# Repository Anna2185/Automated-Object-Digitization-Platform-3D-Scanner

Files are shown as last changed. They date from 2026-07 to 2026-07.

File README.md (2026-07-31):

## Copyright
Copyright © 2026 <b>AM G</b>. All rights reserved. 
This code is published strictly for portfolio demonstration and review purposes. No permission is granted to copy, modify, distribute or use this software for any other purpose.

# Automated Object Digitization Platform (3D-Scanner)
This project is a custom 3D scanner that uses an Arduino, a VL53L1X distance sensor, a stepper motor, and a servo motor. The stepper rotates the object while the VL53L1X measures the distance to the object. The servo then moves the sensor vertically using a linear actuator system so the object can be scanned one layer at a time.

The Arduino handles the physical scanning and sends the measurements to the computer through a serial connection. The Python program receives the data, converts it into 3D coordinates, and creates the different output files.

## Files
### hardware_control Folder
* **hardware_control.ino**: This is the arduino code. It controls the stepper motor, servo motor and VL53L1X sensor. It receives the object height from Python, performs the scan and sends the measurements back to the computer. The scanner takes a measurement every 5 degrees while rotating and moves up 1 mm after each full rotation.
### software_processing Folder
* **main.py**: This is the main Python file. It connects all of the other Python files together. It connects to the Arduino, asks for the object height, starts the scan, collects the data, and then creates the Excel file, point cloud, and STL file.
* **connection.py**: This handles the connection between the computer and Arduino. It finds the available serial ports and lets the user select whichever one is connected to the Arduino.
* **scanning.py**: This handles the scanning process on the Python side. It asks the user for the object height, sends the scan command to the arduino, and collects the measurements returned by the arduino. It also converts the distance measurements into X, Y, and Z coordinates.
* **point_cloud.py**: This handles the 3D point cloud. It displays the scanned points using Matplotlib and uses Open3D to clean up the point cloud and remove some of the noise. It also saves the cleaned point cloud as a PLY file.
* **excel_export.py**: This saves the scan data into an Excel file. The file includes the height, angle, measured distance, and calculated X, Y, and Z coordinates.
* **mesh.py**: This takes the cleaned point cloud and turns it into a 3D mesh using Open3D. The mesh is then exported as an STL file.
#### software_processing/archive/
* **FULL_3D_Scanner_Code.py**: This file is stored in an archive folder within the software_processing folder. It includes all the functions from the main.py, connection.py, scanning.py, point_cloud.py, excel_export.py and mesh.py files. This was the original file I coded in, then once everything was working, I separated all the files into parts to have better structure with actual functions and allow proper documentation.

## Pin Setup
### Stepper Motor (ULN2003 Driver)
* **VCC** -> + (battery 2)
* **GND** -> - (battery 2)
* **IN1, IN2, IN3, IN4** -> Arduino Digital Pins **D8, D9, D10, D11**

### VL53L1X Sensor
* **VCC** -> 5V (Arduino)
* **GND** -> GND (Arduino)
* **SDA** -> SDA (Arduino I2C Bus)
* **SCL** -> SCL (Arduino I2C Bus)
* **GPIO1** -> Arduino Digital Pin **D2**
* **XSHUT** -> 3.3V

### Servo Motor
* **VCC** -> + (battery 1)
* **GND** -> - (battery 1) & GND (Arduino)
* **Signal** -> Arduino Digital Pin **D6**

## How It Works
1. **Upload**: First, the user should open `hardware_control.ino` on Arduino IDE and upload the code to the actual Arduino board (have the board connected to your laptop prior to this)
2. **Launch**: Once that's done run `main.py` and select the Arduino's serial port. You will then be asked to enter the height of the object being scanned in cm
3. **Trigger**: Python sends the height to the Arduino using a command such as `SCAN:10`
4. **Scan**: The Arduino then scans the object by taking distance measurements every 5 degrees as the stepper rotates. After one full rotation, the servo moves the sensor up by 1 mm and the process repeats until the full height of the object has been scanned
5. **Stream**: The Arduino sends each measurement back to Python in the format of "height, angle, distance"
6. **Process**: Python converts these measurements into 3D coordinates and then uses them to create the point cloud and mesh

## Output
After the scan is finished, the program creates three main files:
* **scan_data.xlsx**: Contains the scan measurements and calculated coordinates.
* **clean_point_cloud.ply**: Contains the cleaned 3D point cloud.
* **scan_output.stl**: Contains the final 3D mesh.

## Running the Project
1. First upload `hardware_control.ino` to the Arduino and connect the Arduino to the computer
2. Make sure the required Python libraries are installed, then run: `main.py`
3. Select the Arduino's serial port and enter the height of the object when prompted. The scanner will then run automatically and generate the output files when it is finished

*Note: The current scanner is set up for a maximum object height of 15 cm, with 1 mm vertical resolution and measurements taken every 5 degrees around the object*

## Author
AM G. - [https://github.com/Anna2185](https://github.com/Anna2185?tab=repositories)

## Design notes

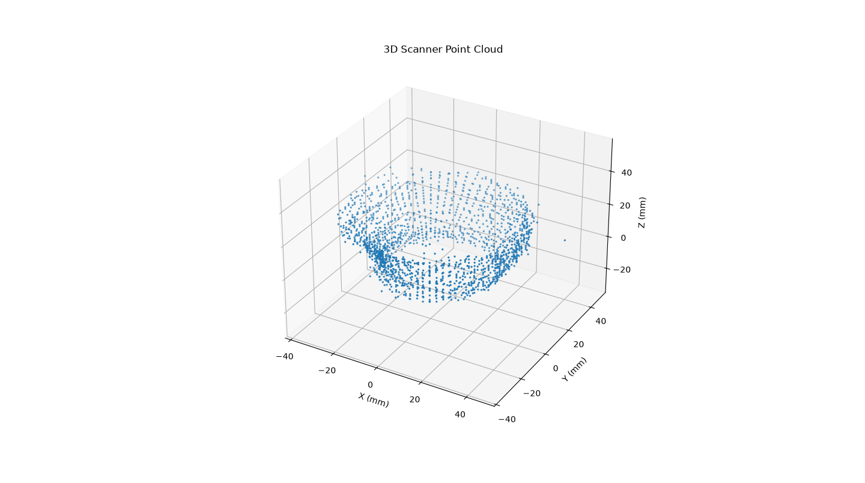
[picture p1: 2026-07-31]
output_samples/Graph Figures/Figure_3.png

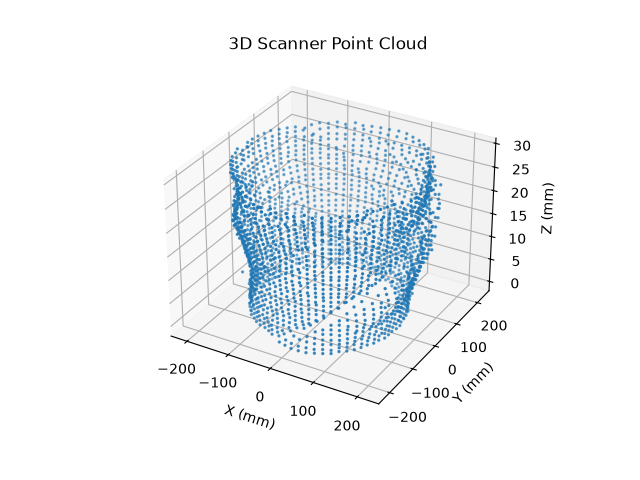
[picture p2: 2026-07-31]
output_samples/Graph Figures/Figure_1.png

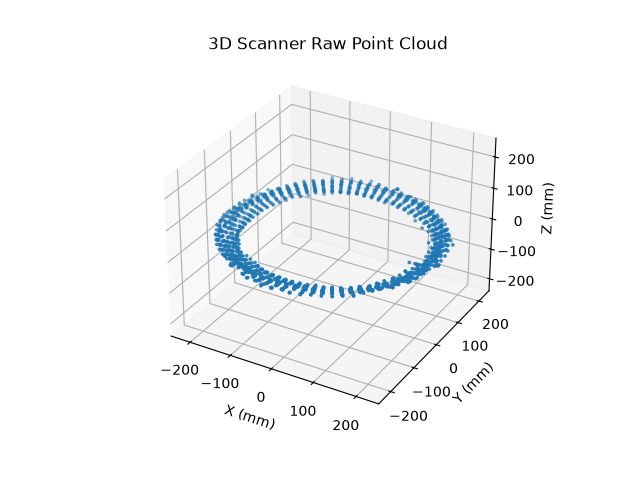
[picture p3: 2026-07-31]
output_samples/Graph Figures/Figure_2.png

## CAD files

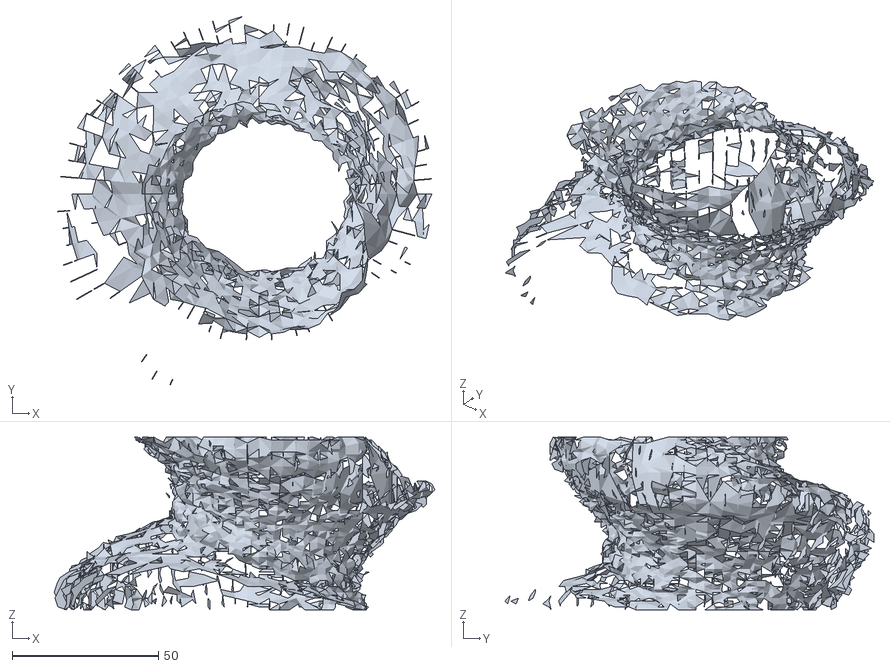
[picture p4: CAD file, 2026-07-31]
output_samples/Graph Figures/scan_output_6.stl
130.0 x 126.0 x 59.0

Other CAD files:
output_samples/clean_point_cloud.ply

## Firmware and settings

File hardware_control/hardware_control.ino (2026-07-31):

//Copyright © 2026 AM G. All rights reserved.
//Published strictly for portfolio demonstration. See README.md for details.

#include <Wire.h>
#include <VL53L1X.h>
#include <Stepper.h>
#include <Servo.h>
#include <math.h>

//Pin definitions (can also be found in the README.md)
/* PINS SET UP
Stepper Motor (ULN2003 Driver): 
  VCC -> + (battery 2)  
  GND -> - (battery 2)
  IN1 IN2 IN3 IN4 -> D8 D9 D10 D11 

VL53L1X Sensor: 
  VCC -> 5V (Arduino) 
  GND -> GND (Arduino)
  SDA -> SDA (Arduino I2C Bus)
  SCL -> SCL (Arduino I2C Bus)
  GPI01 -> D2
  XSHUT -> 3.3V 

Servo Motor: 
  VCC -> + (battery 1)
  GND -> - (battery 1) & GND (Arduino)
  Signal -> D6
*/
const int STEPPER_IN1 = 8;
const int STEPPER_IN2 = 9;
const int STEPPER_IN3 = 10;
const int STEPPER_IN4 = 11;
const int SERVO_PIN = 6;

//Stepper motor configuration
const int STEPS_PER_REVOLUTION = 2048;
const int ROTATION_STEPS = 28;
const float Z_RESOLUTION_MM = 1.0; //adjust this for the change in z you want it to go off of
const float MAX_HEIGHT_MM = 150.0;

//Servo configuration
const int SERVO_START_POS = 180;
const int SERVO_END_POS = 60;
//change # to whatever number of servo degrees equals exactly 1 mm of physical lift on the rig
//const float SERVO_DEGREES_PER_MM = 0.6; 
const float SERVO_DEGREES_PER_MM = 1.5; 

//Objects
Stepper turntable(STEPS_PER_REVOLUTION, STEPPER_IN1, STEPPER_IN3, STEPPER_IN2, STEPPER_IN4);
Servo linearAxis;
VL53L1X distanceSensor;

//Start state
float servoPosition = SERVO_START_POS;
int totalHeightLevels = 0;
float servoStepPerLayer = 0.0;
boolean scanning = false;
bool systemReady = false;

void setup() {
  Serial.begin(115200);
  
  //allow serial to stabilize
  delay(2000);
  Serial.println("BOOTING");
  //clear any old data
  while (Serial.available()) {
    Serial.read();
  }
  
  Wire.begin();
  Wire.setClock(400000);

  //initialize sensor
  distanceSensor.setTimeout(500);
  if (!distanceSensor.init()) {
    Serial.println("[ERR] Sensor init failed");
    while (1) {
      delay(1000);
    }
  }

  distanceSensor.setDistanceMode(VL53L1X::Short);
  distanceSensor.setMeasurementTimingBudget(20000);
  distanceSensor.startContinuous(20);

  //initialize stepper
  turntable.setSpeed(12);

  //initialize servo
  linearAxis.attach(SERVO_PIN);
  delay(500);
  servoPosition = SERVO_START_POS;
  linearAxis.write((int)servoPosition);
  delay(1000);

  //send ready signal multiple times to ensure it's received
  Serial.println("[INIT] System booted");
  delay(100);
  Serial.println("READY");
  delay(100);
  Serial.println("READY");
  
  scanning = false;
  delay(1000);
  Serial.println("READY");
  Serial.flush();
  Serial.println("READY");
  systemReady = true;
}

void loop() {
  if (!systemReady) return;
  
  if (Serial.available() > 0) {
    String cmd = Serial.readStringUntil('\n');
    cmd.trim();

    Serial.print("[CMD] ");
    Serial.println(cmd);

        if (cmd.startsWith("SCAN:")) {
      String heightStr = cmd.substring(5);
      float objectHeightCm = heightStr.toFloat();
      float objectHeightMm = objectHeightCm * 10.0;

      if (objectHeightMm <= 0 || objectHeightMm > MAX_HEIGHT_MM) {
        Serial.println("[ERR] Invalid height");
        return;
      }

      //calculate how many total levels are needed based on user input
      totalHeightLevels = (int)ceil(objectHeightMm / Z_RESOLUTION_MM);

      //ensures a consistent 2mm lift regardless of total layers
      servoStepPerLayer = Z_RESOLUTION_MM * SERVO_DEGREES_PER_MM;

      Serial.print("[DBG] Total levels calculated: ");
      Serial.println(totalHeightLevels);
      Serial.print("[DBG] Fixed Servo step degrees: ");
      Serial.println(servoStepPerLayer);

      //move to start position
      servoPosition = SERVO_START_POS;
      linearAxis.write((int)servoPosition);
      delay(1000);

      scanning = true;
      performScan();
      scanning = false;
      
      Serial.println("SCAN_COMPLETE"); 
    }
  }
}


void performScan() {
  for (int level = 0; level < totalHeightLevels; level++) {
    delay(300);

    for (int angleCount = 0; angleCount < 72; angleCount++) {
      int currentAngle = angleCount * 5;

      uint16_t readingMm = distanceSensor.read();

      if (distanceSensor.timeoutOccurred()) {
        continue;
      }

      //output data in following format: height_mm (level), angle, distance_mm
      float currentHeightMm = level * Z_RESOLUTION_MM;

      Serial.print(currentHeightMm);
      Serial.print(",");
      Serial.print(currentAngle);
      Serial.print(",");
      Serial.println(readingMm);

      turntable.step(ROTATION_STEPS);
      delay(50);
    }

    //move servo up
    if (level < (totalHeightLevels - 1)) {
      servoPosition -= servoStepPerLayer;
      
      //ensure system does not exceed the predefined physical limits
      servoPosition = constrain(servoPosition, SERVO_END_POS, SERVO_START_POS);
      
      //round() ensures smooth accurate accumulation of degrees
      Serial.print("[SERVO] ");
      Serial.println(servoPosition);
      linearAxis.write(round(servoPosition)); 
      delay(500);
    }

  }

  //return to start position
  servoPosition = SERVO_START_POS;
  linearAxis.write((int)servoPosition);
  delay(1000);

}

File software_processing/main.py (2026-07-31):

#Copyright © 2026 AM G. All rights reserved.
#Published strictly for portfolio demonstration. See README.md for details.

import numpy as np
from connection   import find_port, connect
from scanning     import get_object_height, start_scan, collect_data
from excel_export import save_to_excel
from point_cloud  import plot_point_cloud, build_open3d_cloud
from mesh         import generate_mesh


#SETTINGS
#has to match the baud rate set in the Arduino code
BAUD_RATE = 115200

#PHYSICAL SCANNER GEOMETRY
#distance in mm from the Rotation axis to the VL53L1X sensor
#rotation axis center---distance--> Sensor
SENSOR_TO_AXIS_MM = 120.0

#Vertical scanning resolution, arduino moves the sensor 1 mm per level
Z_RESOLUTION_MM = 1.0

#maximum sensor reading distance (in mm)
MAX_SENSOR_DISTANCE_MM = 400.0

#minimum sensor reading distance (in mm)
MIN_SENSOR_DISTANCE_MM = 1.0


#OUTPUT FILES
#output files names for the data
EXCEL_FILE = "scan_data.xlsx"
PLY_FILE   = "clean_point_cloud.ply"
STL_FILE   = "scan_output.stl"


#MAIN FUNCTION
def main():
    """
    The main function of the program which calls on the proper functions for the scanning process and data handling
    Steps: 
        1. Find the Arduino port
        2. Connect to the Arduino via serial
        3. Get the object height from the user
        4. Start the scanning process
        5. Collect raw data and valid points
        6. Close the serial connection
        7. Validate point collection
        8. Save raw data to Excel
        9. Plot the point cloud
        10. Build an Open3D point cloud and export to PLY
        11. Generate a mesh and export to STL
    """
    #1.Select Port
    port = find_port()
    if not port:
        print("No serial devices found. Please connect your arduino to a port and try again")
        return
 
    #2.Serial Connection
    ser = connect(port, BAUD_RATE)
 
    #3.Get Object height
    height_cm = get_object_height()
 
    #4.Start Scan
    start_scan(ser, height_cm)
 
    #5.Data Collection
    raw_data, points = collect_data(
        ser,
        SENSOR_TO_AXIS_MM,
        MIN_SENSOR_DISTANCE_MM,
        MAX_SENSOR_DISTANCE_MM
    )
 
    #6.Close Serial Connection
    ser.close()
    print("\nSerial connection closed")
 
    #7.Validate Point Collection
    if len(points) == 0:
        print("No valid scan points were collected.")
        return
 
    #print the number of valid points collected
    print(f"\nCollected "f"{len(points)} "f"valid points.")
 
    #Convert to numpy arrays for easier processing
    points   = np.array(points,   dtype=float)
    raw_data = np.array(raw_data, dtype=float)
 
    #Print point cloud dimensions
    print("\nPoint cloud dimensions:")
    print("X:", points[:, 0].min(),"to", points[:, 0].max(),"mm")
    print("Y:", points[:, 1].min(),"to", points[:, 1].max(),"mm")
    print("Z:", points[:, 2].min(),"to", points[:, 2].max(),"mm")
 
    #8.Save to Excel
    save_to_excel(raw_data, SENSOR_TO_AXIS_MM, EXCEL_FILE)
 
    #9.Plot Point Cloud
    plot_point_cloud(points)
 
    #10.Build Open3D Cloud (cleaning, normals, PLY export)
    pcd = build_open3d_cloud(points, PLY_FILE)
 
    #11.Generate Mesh (STL export)
    generate_mesh(pcd, STL_FILE)
    
    print("\nDONE")
 
 
if __name__ == "__main__":
    main()

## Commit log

2026-05-13 Add scanner_plot script for Arduino data collection
    This script connects to an Arduino, scans data at specified heights, and generates a 3D scatter plot and an STL file from the collected points.
2026-05-13 Add Arduino code for stepper and distance sensor
2026-05-13 Enhance code with comments and stepper settings
    Added comments for hardware connections and defined new constants for stepper motor settings.
2026-05-13 Refactor Arduino code for clarity and efficiency
    Refactor Arduino code for clarity and efficiency, including variable renaming and improved sensor handling.
2026-05-13 Change measurement time to timing budget for sensor
    Updated measurement time setting for distance sensor.
2026-05-13 Implement timeout check for distance sensor
    Added timeout handling for distance sensor readings.
2026-05-13 Update delay comment in stepper rotation
    Added a comment indicating a potential future change to the delay duration.
2026-05-13 Remove checkmark from STL saved message
2026-05-14 Modify height levels and enhance servo control
    Updated vertical height levels and servo movement logic.
2026-05-19 Refactor Arduino code for stepper and servo control
2026-05-19 Refactor Arduino connection and scanning logic
2026-07-31 Added the Reorganized and Updated Files
    Reorganized the messy code into clean Python and Arduino folders, added a complete guide to the README, and put in the copyright notice
    [clean_point_cloud.ply, scan_data.xlsx, scan_data_6.xlsx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]
2026-07-31 Enhance formatting of pin setup in README
    Formatted pin setup section for better readability.
2026-07-31 Fix formatting in README for motor setup sections
    Correct formatting of section headers for Stepper and Servo Motors.
2026-07-31 Improve formatting for motor and sensor setup
    Updated formatting for hardware setup sections in README.
2026-07-31 Fix formatting of copyright comments
    Removed spaces in copyright comments for consistency.
    [main.py]
2026-07-31 Fix copyright comment formatting
    [hardware_control.ino]
2026-07-31 Fix formatting in main.py and clean up whitespace
    [main.py]
